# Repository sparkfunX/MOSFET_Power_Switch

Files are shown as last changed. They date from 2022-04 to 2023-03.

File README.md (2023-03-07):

SparkFun MOSFET Power Switch
========================================

SparkFun MOSFET Power Switch (https://www.sparkfun.com/products/19799)

[*SparkFun MOSFET Power Switch (COM-19799)*](https://www.sparkfun.com/products/19799)

Does your Arduino need to control a high voltage item, like a 12V LED strip, while needing to be powered as well? Do you want to avoid having multiple power adapters for your project and your Arduino? The MOSFET Power Switch is one of those products that we needed ourselves at SparkFun, so we figured other folks may have the same problem. Power the board with up to 12V and control up to 10A, all while providing sweet sweet 3.3V to your control board.

This board is ideal for turning on and off large loads such as solenoids, LEDs strips, and DC loads that may have back EMF. Simply pull the CTL pin low to activate the load. 3.3V, GND, and VCC are also provided at PTH headers. The load can be inserted into the poke-home connectors or soldered into PTH holes.

The MOSFET ([PSMN7R0-100BS](https://cdn.sparkfun.com/assets/6/9/3/8/1/PSMN7R0-100BS.pdf)) is rated to 100A/100V but we don't recommend you go much above 10A as the PCB traces become the limiter. The board 

Repository Contents
-------------------

* **/Hardware** - Eagle design files (.brd, .sch)

License Information
-------------------

This product is _**open source**_! 

Please review the LICENSE.md file for license information. 

If you have any questions or concerns on licensing, please contact technical support on our [SparkFun forums](https://forum.sparkfun.com/viewforum.php?f=152).

Distributed as-is; no warranty is given.

- Your friends at SparkFun.

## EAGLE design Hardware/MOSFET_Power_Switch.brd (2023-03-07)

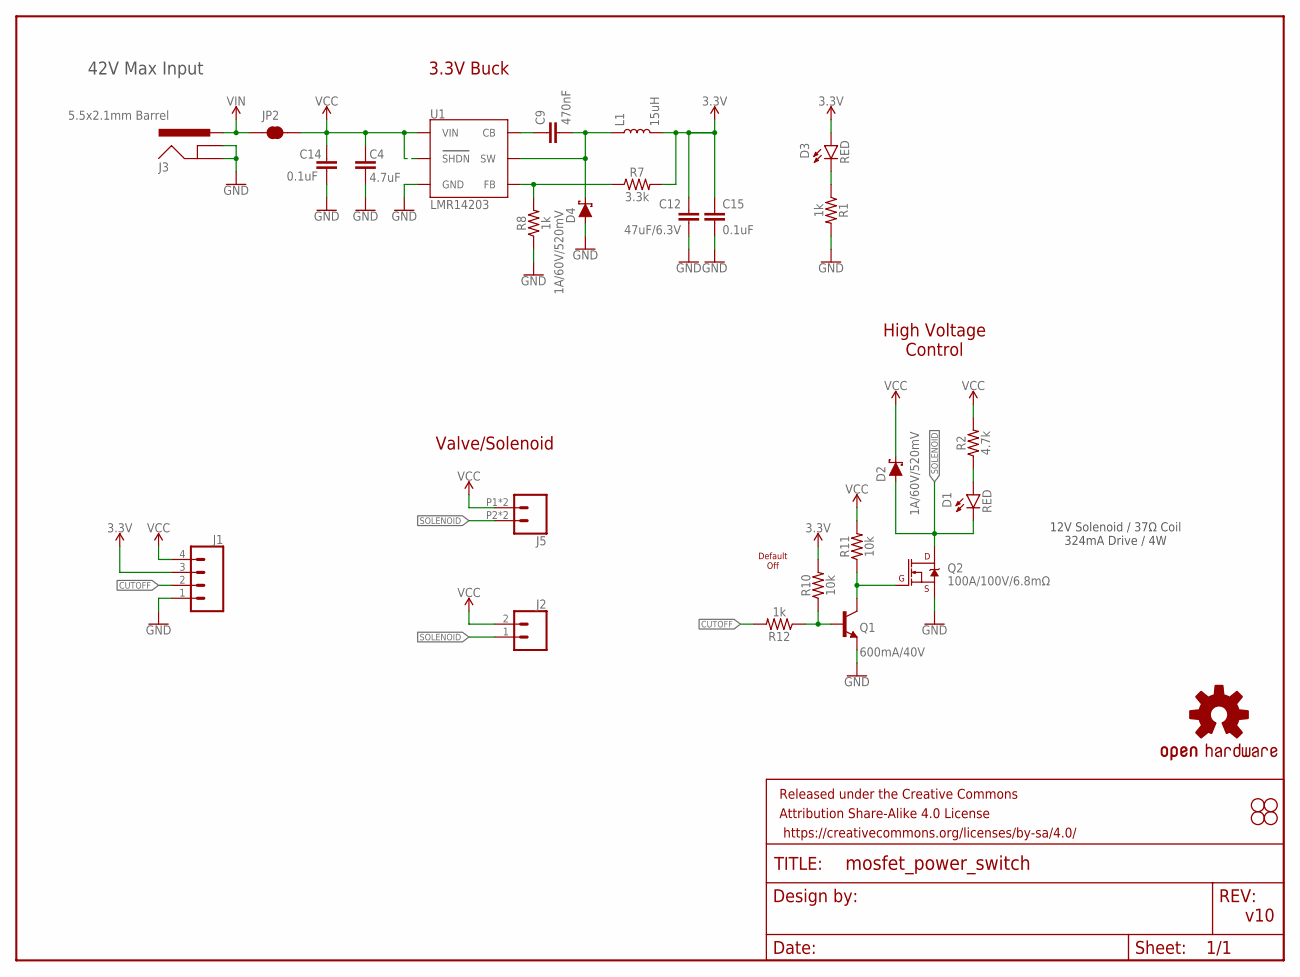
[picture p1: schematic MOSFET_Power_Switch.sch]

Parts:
C4: 4.7uF; 0603
C9: 470nF; 0603
C12: 47uF/6.3V; 0805
C14, C15: 0.1uF; 0603
D1, D3: RED; LED-0603
D2, D4: 1A/60V/520mV; DIODE-MICRO-SMP
FRAME2: FRAME-LETTER; CREATIVE_COMMONS
H1, H2, H3, H4: STAND-OFF
J1: CONN_041X04_NO_SILK_NO_POP; 1X04_NO_SILK
J2: CONN_021X02_NO_SILK; 1X02_NO_SILK
J3: 5.5x2.1mm Barrel; POWER_JACK_SMD
J5: CONN_02SMALL_POKEHOME; 1X02_POKEHOME
JP2: JUMPER-COMBO_2_NC_TRACE; COMBO-JUMPER_2_NC_TRACE
L1: 15uH; INDUCTOR_LQH32
LOGO1: OSHW-LOGOS; OSHW-LOGO-S
Q1: 600mA/40V; SOT23-3
Q2: 100A/100V/6.8mΩ; TO-263/D2PAK
R1, R8, R12: 1k; 0603
R2: 4.7k; 0603
R7: 3.3k; 0603
R10, R11: 10k; 0603
U1: LMR14203; SOT23-6

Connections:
3.3V: C12.1, C15.1, D3.A, J1.3, L1.P$2 (2), R7.2, R10.2
CUTOFF: J1.2, R12.2
GND: C4.2, C12.2, C14.2, C15.2, D4.A, J1.1, J3.GND (GNDBREAK), J3.P$4 (GND), Q1.2 (E), Q2.3 (S), R1.2, R8.1, U1.2 (GND)
unnamed: Q1.3 (C), Q2.1 (G), R11.1
unnamed: D1.A, R2.1
unnamed: D3.C, R1.1
unnamed: R7.1, R8.2, U1.3 (FB)
unnamed: C9.1, U1.1 (CB)
unnamed: Q1.1 (B), R10.1, R12.1
SOLENOID: D1.C, D2.A, J2.1, J5.P2 (2), J5.P4 (2), Q2.2 (D)
VCC: C4.1, C14.1, D2.C, J1.4, J2.2, J5.P1 (1), J5.P3 (1), JP2.2, JP2.4 (2), R2.2, R11.2, U1.4 (SHDN), U1.5 (VIN)
VIN: J3.VIN0 (PWR), JP2.1, JP2.3 (1)
VSW: C9.2, D4.C, L1.P$1 (1), U1.6 (SW)

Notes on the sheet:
v10
Default Off
Valve/Solenoid
High Voltage Control
3.3V Buck
12V Solenoid / 37Ω Coil 324mA Drive / 4W
42V Max Input

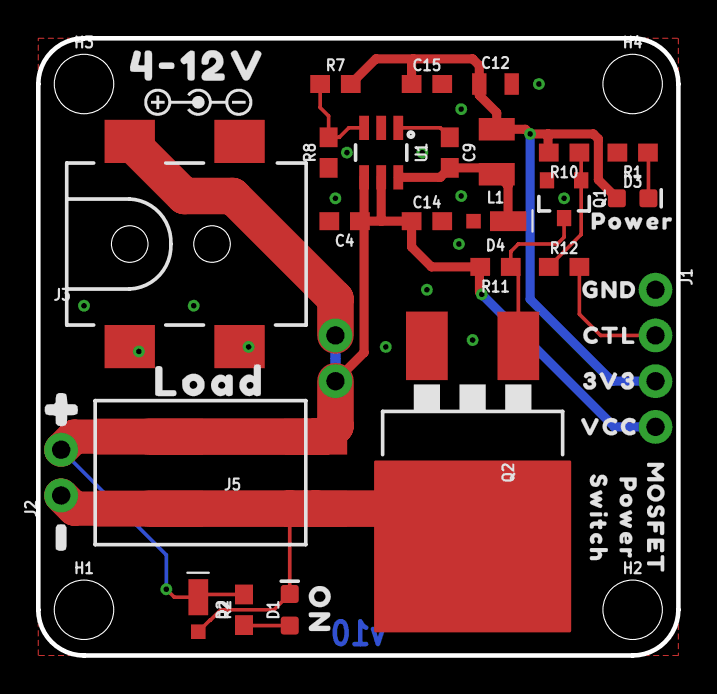
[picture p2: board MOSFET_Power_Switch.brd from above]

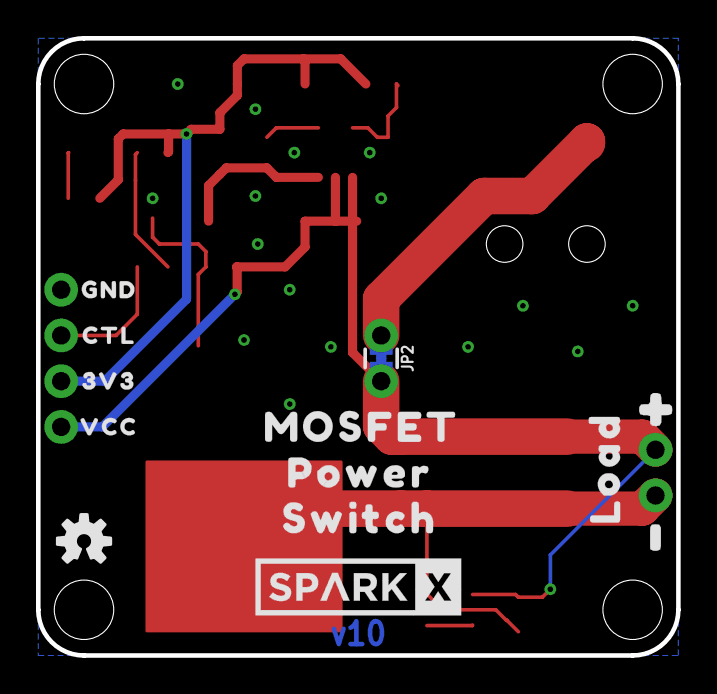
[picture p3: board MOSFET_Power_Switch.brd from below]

Board: 2 copper layers, 35.6 x 34.3 mm, 56 parts (13 on the bottom side), 13 nets.

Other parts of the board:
U$1, U$17: 3V32
U$2: MOSFET0
U$3, U$15: GND0
U$5, U$19: LOAD0
U$6: 4#12V0
U$7, U$18: VCC3
U$8, U$16: CTL0
U$9: POWER1
U$10, U$20: #0
U$11, U$22: #1
U$13: SWITCH2
U$21: SPARKX-LOGO5; SPARKX-LARGE
U$23: POWER0
U$24: MOSFET_0
U$25: POWER_1
U$26: SWITCH_2
U$29: POLARITY_MARKING_CENTER_POSITIVE#JPG
U$49: ON0

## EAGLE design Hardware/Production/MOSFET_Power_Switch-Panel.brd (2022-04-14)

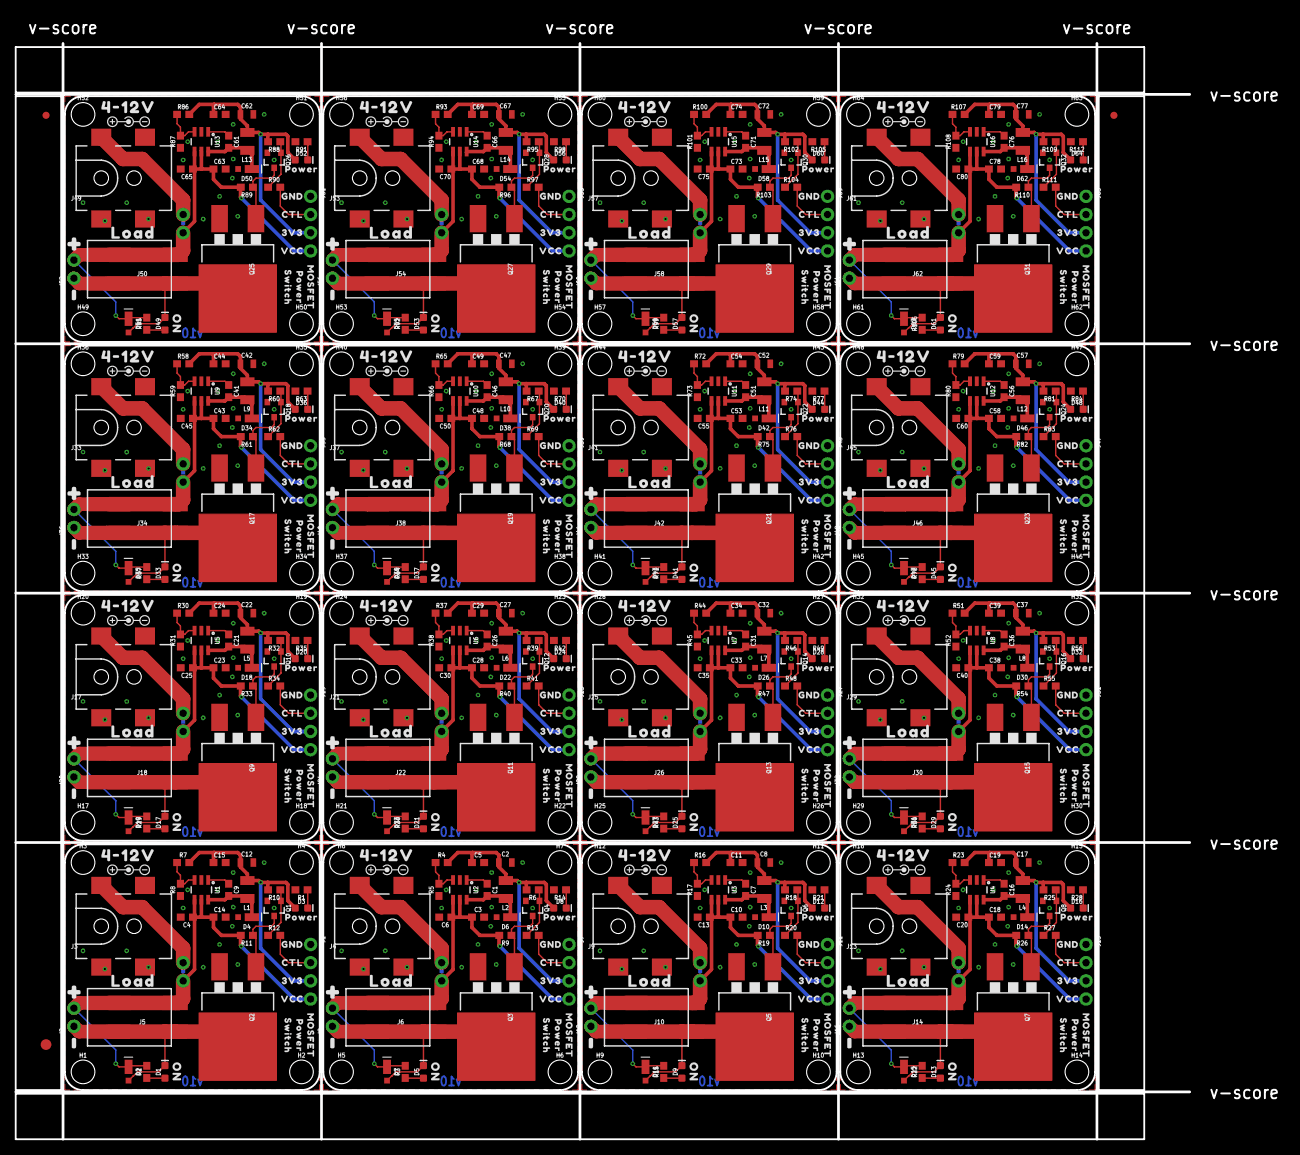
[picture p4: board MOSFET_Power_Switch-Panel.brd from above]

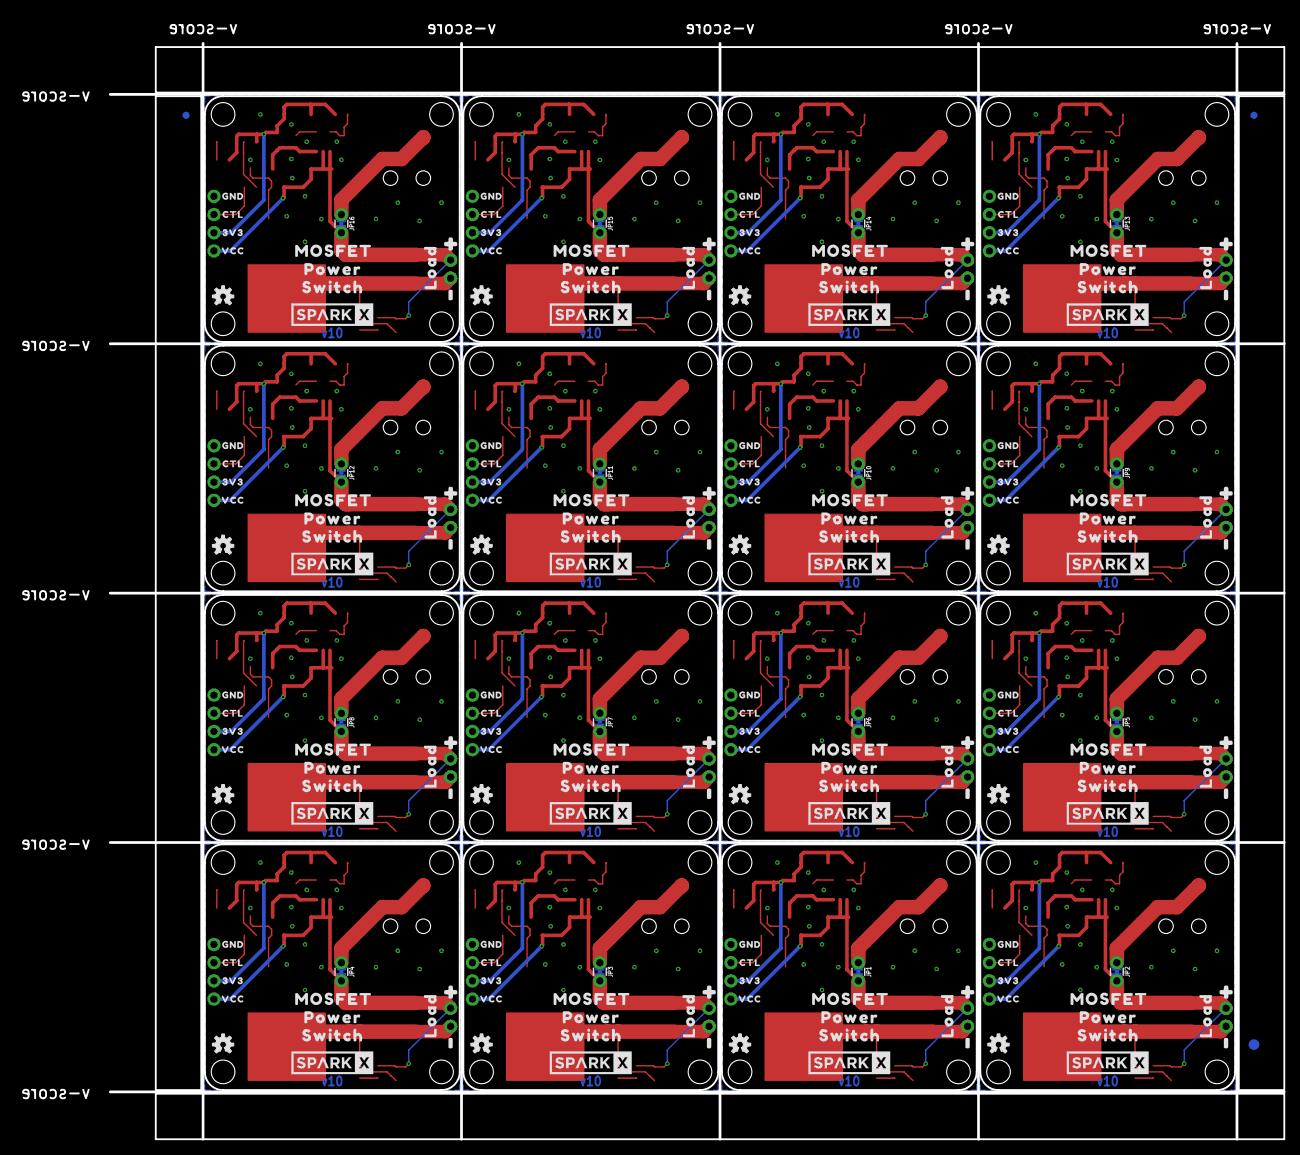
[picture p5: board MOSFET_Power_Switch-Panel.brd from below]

Board: 2 copper layers, 163.8 x 152.9 mm, 886 parts (211 on the bottom side), 208 nets.

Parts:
C1, C7, C9, C16, C21, C26, C31, C36, C41, C46, C51, C56, C61, C66, C71, C76: 470nF; 0603
C2, C8, C12, C17, C22, C27, C32, C37, C42, C47, C52, C57, C62, C67, C72, C77: 47uF/6.3V; 0805
C3, C5, C10, C11, C14, C15, C18, C19, C23, C24, C28, C29, C33, C34, C38, C39, C43, C44, C48, C49, C53, C54, C58, C59, C63, C64, C68, C69, C73, C74, C78, C79: 0.1uF; 0603
C4, C6, C13, C20, C25, C30, C35, C40, C45, C50, C55, C60, C65, C70, C75, C80: 4.7uF; 0603
D1, D3, D5, D8, D9, D12, D13, D16, D17, D20, D21, D24, D25, D28, D29, D32, D33, D36, D37, D40, D41, D44, D45, D48, D49, D52, D53, D56, D57, D60, D61, D64: RED; LED-0603
D2, D4, D6, D7, D10, D11, D14, D15, D18, D19, D22, D23, D26, D27, D30, D31, D34, D35, D38, D39, D42, D43, D46, D47, D50, D51, D54, D55, D58, D59, D62, D63: 1A/60V/520mV; DIODE-MICRO-SMP
E$1, E$2, E$3, E$4: FIDUCIAL-1X2
E$5, E$6: FIDUCIAL-1.5X3
H1, H2, H3, H4, H5, H6, H7, H8, H9, H10, H11, H12, H13, H14, H15, H16, H17, H18, H19, H20, H21, H22, H23, H24, H25, H26, H27, H28, H29, H30, H31, H32, H33, H34, H35, H36, H37, H38, H39, H40, H41, H42, H43, H44, H45, H46, H47, H48, H49, H50, H51, H52, H53, H54, H55, H56, H57, H58, H59, H60, H61, H62, H63, H64: STAND-OFF
J1, J7, J11, J15, J19, J23, J27, J31, J35, J39, J43, J47, J51, J55, J59, J63: 1X04_NO_SILK
J2, J8, J12, J16, J20, J24, J28, J32, J36, J40, J44, J48, J52, J56, J60, J64: 1X02_NO_SILK
J3, J4, J9, J13, J17, J21, J25, J29, J33, J37, J41, J45, J49, J53, J57, J61: 5.5x2.1mm Barrel; POWER_JACK_SMD
J5, J6, J10, J14, J18, J22, J26, J30, J34, J38, J42, J46, J50, J54, J58, J62: 1X02_POKEHOME
JP1, JP2, JP3, JP4, JP5, JP6, JP7, JP8, JP9, JP10, JP11, JP12, JP13, JP14, JP15, JP16: JUMPER-COMBO_2_NC_TRACE; COMBO-JUMPER_2_NC_TRACE
L1, L2, L3, L4, L5, L6, L7, L8, L9, L10, L11, L12, L13, L14, L15, L16: 15uH; INDUCTOR_LQH32
LOGO1, LOGO2, LOGO3, LOGO4, LOGO5, LOGO6, LOGO7, LOGO8, LOGO9, LOGO10, LOGO11, LOGO12, LOGO13, LOGO14, LOGO15, LOGO16: OSHW-LOGOS; OSHW-LOGO-S
Q1, Q4, Q6, Q8, Q10, Q12, Q14, Q16, Q18, Q20, Q22, Q24, Q26, Q28, Q30, Q32: 600mA/40V; SOT23-3
Q2, Q3, Q5, Q7, Q9, Q11, Q13, Q15, Q17, Q19, Q21, Q23, Q25, Q27, Q29, Q31: 100A/100V/6.8mΩ; TO-263/D2PAK
R1, R5, R8, R12, R13, R14, R17, R20, R21, R24, R27, R28, R31, R34, R35, R38, R41, R42, R45, R48, R49, R52, R55, R56, R59, R62, R63, R66, R69, R70, R73, R76, R77, R80, R83, R84, R87, R90, R91, R94, R97, R98, R101, R104, R105, R108, R111, R112: 1k; 0603
R2, R3, R15, R22, R29, R36, R43, R50, R57, R64, R71, R78, R85, R92, R99, R106: 4.7k; 0603
R4, R7, R16, R23, R30, R37, R44, R51, R58, R65, R72, R79, R86, R93, R100, R107: 3.3k; 0603
R6, R9, R10, R11, R18, R19, R25, R26, R32, R33, R39, R40, R46, R47, R53, R54, R60, R61, R67, R68, R74, R75, R81, R82, R88, R89, R95, R96, R102, R103, R109, R110: 10k; 0603
U1, U2, U3, U4, U5, U6, U7, U8, U9, U10, U11, U12, U13, U14, U15, U16: LMR14203; SOT23-6
U$1, U$17, U$31, U$38, U$57, U$64, U$82, U$89, U$107, U$114, U$132, U$139, U$157, U$164, U$182, U$189, U$207, U$214, U$232, U$239, U$257, U$264, U$282, U$289, U$307, U$314, U$332, U$339, U$357, U$364, U$382, U$389: 3V32
U$2, U$43, U$69, U$94, U$119, U$144, U$169, U$194, U$219, U$244, U$269, U$294, U$319, U$344, U$369, U$394: MOSFET0
U$3, U$15, U$32, U$36, U$58, U$62, U$83, U$87, U$108, U$112, U$133, U$137, U$158, U$162, U$183, U$187, U$208, U$212, U$233, U$237, U$258, U$262, U$283, U$287, U$308, U$312, U$333, U$337, U$358, U$362, U$383, U$387: GND0
U$4, U$21, U$51, U$76, U$101, U$126, U$151, U$176, U$201, U$226, U$251, U$276, U$301, U$326, U$351, U$376: SPARKX-LOGO5; SPARKX-LARGE
U$5, U$19, U$30, U$40, U$56, U$66, U$81, U$91, U$106, U$116, U$131, U$141, U$156, U$166, U$181, U$191, U$206, U$216, U$231, U$241, U$256, U$266, U$281, U$291, U$306, U$316, U$331, U$341, U$356, U$366, U$381, U$391: LOAD0
U$6, U$35, U$61, U$86, U$111, U$136, U$161, U$186, U$211, U$236, U$261, U$286, U$311, U$336, U$361, U$386: 4#12V0
U$7, U$18, U$33, U$39, U$59, U$65, U$84, U$90, U$109, U$115, U$134, U$140, U$159, U$165, U$184, U$190, U$209, U$215, U$234, U$240, U$259, U$265, U$284, U$290, U$309, U$315, U$334, U$340, U$359, U$365, U$384, U$390: VCC3
U$8, U$16, U$34, U$37, U$60, U$63, U$85, U$88, U$110, U$113, U$135, U$138, U$160, U$163, U$185, U$188, U$210, U$213, U$235, U$238, U$260, U$263, U$285, U$288, U$310, U$313, U$335, U$338, U$360, U$363, U$385, U$388: CTL0
U$9, U$44, U$70, U$95, U$120, U$145, U$170, U$195, U$220, U$245, U$270, U$295, U$320, U$345, U$370, U$395: POWER1
U$10, U$20, U$27, U$41, U$54, U$67, U$79, U$92, U$104, U$117, U$129, U$142, U$154, U$167, U$179, U$192, U$204, U$217, U$229, U$242, U$254, U$267, U$279, U$292, U$304, U$317, U$329, U$342, U$354, U$367, U$379, U$392: #0
U$11, U$22, U$28, U$42, U$55, U$68, U$80, U$93, U$105, U$118, U$130, U$143, U$155, U$168, U$180, U$193, U$205, U$218, U$230, U$243, U$255, U$268, U$280, U$293, U$305, U$318, U$330, U$343, U$355, U$368, U$380, U$393: #1
U$12, U$49, U$52, U$77, U$102, U$127, U$152, U$177, U$202, U$227, U$252, U$277, U$302, U$327, U$352, U$377: ON0
U$13, U$45, U$71, U$96, U$121, U$146, U$171, U$196, U$221, U$246, U$271, U$296, U$321, U$346, U$371, U$396: SWITCH2
U$14, U$29, U$53, U$78, U$103, U$128, U$153, U$178, U$203, U$228, U$253, U$278, U$303, U$328, U$353, U$378: POLARITY_MARKING_CENTER_POSITIVE#JPG
U$23, U$46, U$72, U$97, U$122, U$147, U$172, U$197, U$222, U$247, U$272, U$297, U$322, U$347, U$372, U$397: POWER0
U$24, U$47, U$73, U$98, U$123, U$148, U$173, U$198, U$223, U$248, U$273, U$298, U$323, U$348, U$373, U$398: MOSFET_0
U$25, U$48, U$74, U$99, U$124, U$149, U$174, U$199, U$224, U$249, U$274, U$299, U$324, U$349, U$374, U$399: POWER_1
U$26, U$50, U$75, U$100, U$125, U$150, U$175, U$200, U$225, U$250, U$275, U$300, U$325, U$350, U$375, U$400: SWITCH_2

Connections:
3.3V: C12.1, C15.1, D3.A, J1.3, L1.P$2, R7.2, R10.2
3.3V1: C2.1, C5.1, D8.A, J7.3, L2.P$2, R4.2, R6.2
3.3V2: C8.1, C11.1, D12.A, J11.3, L3.P$2, R16.2, R18.2
3.3V3: C17.1, C19.1, D16.A, J15.3, L4.P$2, R23.2, R25.2
3.3V4: C22.1, C24.1, D20.A, J19.3, L5.P$2, R30.2, R32.2
3.3V5: C27.1, C29.1, D24.A, J23.3, L6.P$2, R37.2, R39.2
3.3V6: C32.1, C34.1, D28.A, J27.3, L7.P$2, R44.2, R46.2
3.3V7: C37.1, C39.1, D32.A, J31.3, L8.P$2, R51.2, R53.2
3.3V8: C42.1, C44.1, D36.A, J35.3, L9.P$2, R58.2, R60.2
3.3V9: C47.1, C49.1, D40.A, J39.3, L10.P$2, R65.2, R67.2
3.3V10: C52.1, C54.1, D44.A, J43.3, L11.P$2, R72.2, R74.2
3.3V11: C57.1, C59.1, D48.A, J47.3, L12.P$2, R79.2, R81.2
3.3V12: C62.1, C64.1, D52.A, J51.3, L13.P$2, R86.2, R88.2
3.3V13: C67.1, C69.1, D56.A, J55.3, L14.P$2, R93.2, R95.2
3.3V14: C72.1, C74.1, D60.A, J59.3, L15.P$2, R100.2, R102.2
3.3V15: C77.1, C79.1, D64.A, J63.3, L16.P$2, R107.2, R109.2
CUTOFF: J1.2, R12.2
CUTOFF1: J7.2, R13.2
CUTOFF2: J11.2, R20.2
CUTOFF3: J15.2, R27.2
CUTOFF4: J19.2, R34.2
CUTOFF5: J23.2, R41.2
CUTOFF6: J27.2, R48.2
CUTOFF7: J31.2, R55.2
CUTOFF8: J35.2, R62.2
CUTOFF9: J39.2, R69.2
CUTOFF10: J43.2, R76.2
CUTOFF11: J47.2, R83.2
CUTOFF12: J51.2, R90.2
CUTOFF13: J55.2, R97.2
CUTOFF14: J59.2, R104.2
CUTOFF15: J63.2, R111.2
GND: C4.2, C12.2, C14.2, C15.2, D4.A, J1.1, J3.GND, J3.P$4, Q1.2, Q2.3, R1.2, R8.1, U1.2
GND1: C2.2, C3.2, C5.2, C6.2, D6.A, J4.GND, J4.P$4, J7.1, Q3.3, Q4.2, R5.1, R14.2, U2.2
GND2: C8.2, C10.2, C11.2, C13.2, D10.A, J9.GND, J9.P$4, J11.1, Q5.3, Q6.2, R17.1, R21.2, U3.2
GND3: C17.2, C18.2, C19.2, C20.2, D14.A, J13.GND, J13.P$4, J15.1, Q7.3, Q8.2, R24.1, R28.2, U4.2
GND4: C22.2, C23.2, C24.2, C25.2, D18.A, J17.GND, J17.P$4, J19.1, Q9.3, Q10.2, R31.1, R35.2, U5.2
GND5: C27.2, C28.2, C29.2, C30.2, D22.A, J21.GND, J21.P$4, J23.1, Q11.3, Q12.2, R38.1, R42.2, U6.2
GND6: C32.2, C33.2, C34.2, C35.2, D26.A, J25.GND, J25.P$4, J27.1, Q13.3, Q14.2, R45.1, R49.2, U7.2
GND7: C37.2, C38.2, C39.2, C40.2, D30.A, J29.GND, J29.P$4, J31.1, Q15.3, Q16.2, R52.1, R56.2, U8.2
GND8: C42.2, C43.2, C44.2, C45.2, D34.A, J33.GND, J33.P$4, J35.1, Q17.3, Q18.2, R59.1, R63.2, U9.2
GND9: C47.2, C48.2, C49.2, C50.2, D38.A, J37.GND, J37.P$4, J39.1, Q19.3, Q20.2, R66.1, R70.2, U10.2
GND10: C52.2, C53.2, C54.2, C55.2, D42.A, J41.GND, J41.P$4, J43.1, Q21.3, Q22.2, R73.1, R77.2, U11.2
GND11: C57.2, C58.2, C59.2, C60.2, D46.A, J45.GND, J45.P$4, J47.1, Q23.3, Q24.2, R80.1, R84.2, U12.2
GND12: C62.2, C63.2, C64.2, C65.2, D50.A, J49.GND, J49.P$4, J51.1, Q25.3, Q26.2, R87.1, R91.2, U13.2
GND13: C67.2, C68.2, C69.2, C70.2, D54.A, J53.GND, J53.P$4, J55.1, Q27.3, Q28.2, R94.1, R98.2, U14.2
GND14: C72.2, C73.2, C74.2, C75.2, D58.A, J57.GND, J57.P$4, J59.1, Q29.3, Q30.2, R101.1, R105.2, U15.2
GND15: C77.2, C78.2, C79.2, C80.2, D62.A, J61.GND, J61.P$4, J63.1, Q31.3, Q32.2, R108.1, R112.2, U16.2
unnamed: Q1.3, Q2.1, R11.1
unnamed: D1.A, R2.1
unnamed: D3.C, R1.1
unnamed: D5.A, R3.1
unnamed: R7.1, R8.2, U1.3
unnamed: R4.1, R5.2, U2.3
unnamed: C1.1, U2.1
unnamed: Q3.1, Q4.3, R9.1
unnamed: Q4.1, R6.1, R13.1
unnamed: C9.1, U1.1
unnamed: D8.C, R14.1
unnamed: Q1.1, R10.1, R12.1
unnamed: D9.A, R15.1
unnamed: R16.1, R17.2, U3.3
unnamed: C7.1, U3.1
unnamed: Q5.1, Q6.3, R19.1
unnamed: Q6.1, R18.1, R20.1
unnamed: D12.C, R21.1
unnamed: D13.A, R22.1
unnamed: R23.1, R24.2, U4.3
unnamed: C16.1, U4.1
unnamed: Q7.1, Q8.3, R26.1
unnamed: Q8.1, R25.1, R27.1
unnamed: D16.C, R28.1
unnamed: D17.A, R29.1
unnamed: R30.1, R31.2, U5.3
unnamed: C21.1, U5.1
unnamed: Q9.1, Q10.3, R33.1
unnamed: Q10.1, R32.1, R34.1
unnamed: D20.C, R35.1
unnamed: D21.A, R36.1
unnamed: R37.1, R38.2, U6.3
unnamed: C26.1, U6.1
unnamed: Q11.1, Q12.3, R40.1
unnamed: Q12.1, R39.1, R41.1
unnamed: D24.C, R42.1
unnamed: D25.A, R43.1
unnamed: R44.1, R45.2, U7.3
unnamed: C31.1, U7.1
unnamed: Q13.1, Q14.3, R47.1
unnamed: Q14.1, R46.1, R48.1
unnamed: D28.C, R49.1
unnamed: D29.A, R50.1
unnamed: R51.1, R52.2, U8.3
unnamed: C36.1, U8.1
unnamed: Q15.1, Q16.3, R54.1
unnamed: Q16.1, R53.1, R55.1
unnamed: D32.C, R56.1
unnamed: D33.A, R57.1
unnamed: R58.1, R59.2, U9.3
unnamed: C41.1, U9.1
unnamed: Q17.1, Q18.3, R61.1
unnamed: Q18.1, R60.1, R62.1
unnamed: D36.C, R63.1
unnamed: D37.A, R64.1
unnamed: R65.1, R66.2, U10.3
unnamed: C46.1, U10.1
unnamed: Q19.1, Q20.3, R68.1
unnamed: Q20.1, R67.1, R69.1
unnamed: D40.C, R70.1
unnamed: D41.A, R71.1
unnamed: R72.1, R73.2, U11.3
unnamed: C51.1, U11.1
unnamed: Q21.1, Q22.3, R75.1
unnamed: Q22.1, R74.1, R76.1
unnamed: D44.C, R77.1
unnamed: D45.A, R78.1
unnamed: R79.1, R80.2, U12.3
unnamed: C56.1, U12.1
unnamed: Q23.1, Q24.3, R82.1
unnamed: Q24.1, R81.1, R83.1
unnamed: D48.C, R84.1
unnamed: D49.A, R85.1
unnamed: R86.1, R87.2, U13.3
unnamed: C61.1, U13.1
unnamed: Q25.1, Q26.3, R89.1
unnamed: Q26.1, R88.1, R90.1
unnamed: D52.C, R91.1
unnamed: D53.A, R92.1
unnamed: R93.1, R94.2, U14.3
unnamed: C66.1, U14.1
unnamed: Q27.1, Q28.3, R96.1
unnamed: Q28.1, R95.1, R97.1
unnamed: D56.C, R98.1
unnamed: D57.A, R99.1
unnamed: R100.1, R101.2, U15.3
unnamed: C71.1, U15.1
unnamed: Q29.1, Q30.3, R103.1
unnamed: Q30.1, R102.1, R104.1
unnamed: D60.C, R105.1
unnamed: D61.A, R106.1
unnamed: R107.1, R108.2, U16.3
unnamed: C76.1, U16.1
unnamed: Q31.1, Q32.3, R110.1
unnamed: Q32.1, R109.1, R111.1
unnamed: D64.C, R112.1
SOLENOID: D1.C, D2.A, J2.1, J5.P2, J5.P4, Q2.2
SOLENOID1: D5.C, D7.A, J6.P2, J6.P4, J8.1, Q3.2
SOLENOID2: D9.C, D11.A, J10.P2, J10.P4, J12.1, Q5.2
SOLENOID3: D13.C, D15.A, J14.P2, J14.P4, J16.1, Q7.2
SOLENOID4: D17.C, D19.A, J18.P2, J18.P4, J20.1, Q9.2
SOLENOID5: D21.C, D23.A, J22.P2, J22.P4, J24.1, Q11.2
SOLENOID6: D25.C, D27.A, J26.P2, J26.P4, J28.1, Q13.2
SOLENOID7: D29.C, D31.A, J30.P2, J30.P4, J32.1, Q15.2
SOLENOID8: D33.C, D35.A, J34.P2, J34.P4, J36.1, Q17.2
SOLENOID9: D37.C, D39.A, J38.P2, J38.P4, J40.1, Q19.2
SOLENOID10: D41.C, D43.A, J42.P2, J42.P4, J44.1, Q21.2
SOLENOID11: D45.C, D47.A, J46.P2, J46.P4, J48.1, Q23.2
SOLENOID12: D49.C, D51.A, J50.P2, J50.P4, J52.1, Q25.2
SOLENOID13: D53.C, D55.A, J54.P2, J54.P4, J56.1, Q27.2
SOLENOID14: D57.C, D59.A, J58.P2, J58.P4, J60.1, Q29.2
SOLENOID15: D61.C, D63.A, J62.P2, J62.P4, J64.1, Q31.2
VCC: C4.1, C14.1, D2.C, J1.4, J2.2, J5.P1, J5.P3, JP2.2, JP2.4, R2.2, R11.2, U1.4, U1.5
VCC1: C3.1, C6.1, D7.C, J6.P1, J6.P3, J7.4, J8.2, JP1.2, JP1.4, R3.2, R9.2, U2.4, U2.5
VCC2: C10.1, C13.1, D11.C, J10.P1, J10.P3, J11.4, J12.2, JP3.2, JP3.4, R15.2, R19.2, U3.4, U3.5
VCC3: C18.1, C20.1, D15.C, J14.P1, J14.P3, J15.4, J16.2, JP4.2, JP4.4, R22.2, R26.2, U4.4, U4.5
VCC4: C23.1, C25.1, D19.C, J18.P1, J18.P3, J19.4, J20.2, JP5.2, JP5.4, R29.2, R33.2, U5.4, U5.5
VCC5: C28.1, C30.1, D23.C, J22.P1, J22.P3, J23.4, J24.2, JP6.2, JP6.4, R36.2, R40.2, U6.4, U6.5
VCC6: C33.1, C35.1, D27.C, J26.P1, J26.P3, J27.4, J28.2, JP7.2, JP7.4, R43.2, R47.2, U7.4, U7.5
VCC7: C38.1, C40.1, D31.C, J30.P1, J30.P3, J31.4, J32.2, JP8.2, JP8.4, R50.2, R54.2, U8.4, U8.5
VCC8: C43.1, C45.1, D35.C, J34.P1, J34.P3, J35.4, J36.2, JP9.2, JP9.4, R57.2, R61.2, U9.4, U9.5
VCC9: C48.1, C50.1, D39.C, J38.P1, J38.P3, J39.4, J40.2, JP10.2, JP10.4, R64.2, R68.2, U10.4, U10.5
VCC10: C53.1, C55.1, D43.C, J42.P1, J42.P3, J43.4, J44.2, JP11.2, JP11.4, R71.2, R75.2, U11.4, U11.5
VCC11: C58.1, C60.1, D47.C, J46.P1, J46.P3, J47.4, J48.2, JP12.2, JP12.4, R78.2, R82.2, U12.4, U12.5
VCC12: C63.1, C65.1, D51.C, J50.P1, J50.P3, J51.4, J52.2, JP13.2, JP13.4, R85.2, R89.2, U13.4, U13.5
VCC13: C68.1, C70.1, D55.C, J54.P1, J54.P3, J55.4, J56.2, JP14.2, JP14.4, R92.2, R96.2, U14.4, U14.5
VCC14: C73.1, C75.1, D59.C, J58.P1, J58.P3, J59.4, J60.2, JP15.2, JP15.4, R99.2, R103.2, U15.4, U15.5
VCC15: C78.1, C80.1, D63.C, J62.P1, J62.P3, J63.4, J64.2, JP16.2, JP16.4, R106.2, R110.2, U16.4, U16.5
VIN: J3.VIN0, JP2.1, JP2.3
VIN1: J4.VIN0, JP1.1, JP1.3
VIN2: J9.VIN0, JP3.1, JP3.3
VIN3: J13.VIN0, JP4.1, JP4.3
VIN4: J17.VIN0, JP5.1, JP5.3
VIN5: J21.VIN0, JP6.1, JP6.3
VIN6: J25.VIN0, JP7.1, JP7.3
VIN7: J29.VIN0, JP8.1, JP8.3
VIN8: J33.VIN0, JP9.1, JP9.3
VIN9: J37.VIN0, JP10.1, JP10.3
VIN10: J41.VIN0, JP11.1, JP11.3
VIN11: J45.VIN0, JP12.1, JP12.3
VIN12: J49.VIN0, JP13.1, JP13.3
VIN13: J53.VIN0, JP14.1, JP14.3
VIN14: J57.VIN0, JP15.1, JP15.3
VIN15: J61.VIN0, JP16.1, JP16.3
VSW: C9.2, D4.C, L1.P$1, U1.6
VSW1: C1.2, D6.C, L2.P$1, U2.6
VSW2: C7.2, D10.C, L3.P$1, U3.6
VSW3: C16.2, D14.C, L4.P$1, U4.6
VSW4: C21.2, D18.C, L5.P$1, U5.6
VSW5: C26.2, D22.C, L6.P$1, U6.6
VSW6: C31.2, D26.C, L7.P$1, U7.6
VSW7: C36.2, D30.C, L8.P$1, U8.6
VSW8: C41.2, D34.C, L9.P$1, U9.6
VSW9: C46.2, D38.C, L10.P$1, U10.6
VSW10: C51.2, D42.C, L11.P$1, U11.6
VSW11: C56.2, D46.C, L12.P$1, U12.6
VSW12: C61.2, D50.C, L13.P$1, U13.6
VSW13: C66.2, D54.C, L14.P$1, U14.6
VSW14: C71.2, D58.C, L15.P$1, U15.6
VSW15: C76.2, D62.C, L16.P$1, U16.6

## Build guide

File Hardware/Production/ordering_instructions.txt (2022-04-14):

panel size, 158x153mm
PCB thickness, 1.6mm
number of layers, 2
soldermask color, Unknown
silkscreen color, White
oz copper, 1oz
finish, HASL lead free
stencils, none
pcs per panel, 16
min trace width, 0.2032mm / 0.0080in
min drill size, 0.3048mm / 0.0120in

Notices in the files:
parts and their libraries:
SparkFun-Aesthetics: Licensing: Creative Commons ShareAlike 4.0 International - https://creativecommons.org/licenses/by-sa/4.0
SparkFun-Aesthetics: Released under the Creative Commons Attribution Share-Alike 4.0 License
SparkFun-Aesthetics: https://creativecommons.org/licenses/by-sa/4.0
